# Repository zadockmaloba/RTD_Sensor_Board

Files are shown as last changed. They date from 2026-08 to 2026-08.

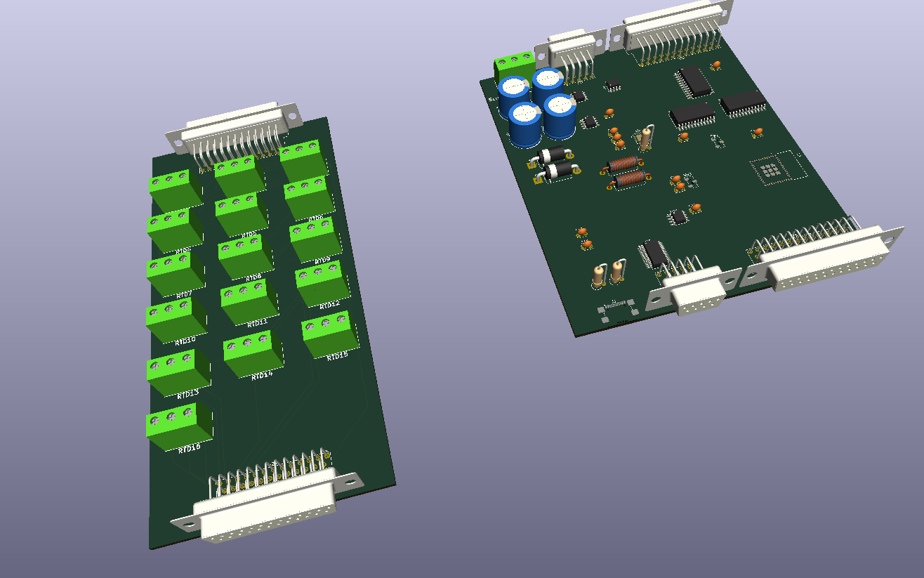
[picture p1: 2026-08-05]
schematics/sensor_node_custom_board.png

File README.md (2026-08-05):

# Zadock Maloba - Instrumentation & Control Engineer Design Challenge

## The System

A lab-scale thermal test bench. Sixteen RTDs are distributed along a heated circuit; a
coolant admission valve opens and closes to hold the circuit within band. The bench runs
unattended for days at a time, and the resulting temperature record is the deliverable that
engineers downstream actually care about.

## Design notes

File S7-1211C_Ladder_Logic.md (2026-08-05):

# S7-1211C Ladder Logic

## 1. Purpose

This document describes the derived ladder logic for the Siemens S7-1211C CPU with CB1241 communication module used in the thermal test bench. The logic reads RTD temperature data from the IPC via Modbus, evaluates interlock conditions, and controls the coolant valve.

## 2. Assumptions

- The PLC uses the CB1241 for RS-485 Modbus communication with the IPC.
- The IPC exposes RTD temperatures and status values in Modbus registers.
- The PLC executes a read cycle every `100 ms`.
- The valve coil is controlled by output `Q0.0`.
- Valve feedback is available in Modbus register `VALVE_STATUS`.

## 3. Data Block Mapping

Use `DB1` to map Modbus register values into PLC memory.

| DB1 Offset | Description |
|---|---|
| `DB1.W0` | SYSTEM_STATUS |
| `DB1.W1` | NODE_HEALTH |
| `DB1.W2` | RTD_01 |
| `DB1.W3` | RTD_02 |
| `DB1.W4` | RTD_03 |
| `DB1.W5` | RTD_04 |
| `DB1.W6` | RTD_05 |
| `DB1.W7` | RTD_06 |
| `DB1.W8` | RTD_07 |
| `DB1.W9` | RTD_08 |
| `DB1.W10` | RTD_09 |
| `DB1.W11` | RTD_10 |
| `DB1.W12` | RTD_11 |
| `DB1.W13` | RTD_12 |
| `DB1.W14` | RTD_13 |
| `DB1.W15` | RTD_14 |
| `DB1.W16` | RTD_15 |
| `DB1.W17` | RTD_16 |
| `DB1.W18` | RTD_FAULT_BITMAP |
| `DB1.W19` | INTERLOCK_SOURCE |
| `DB1.W20` | VALVE_COMMAND |
| `DB1.W21` | VALVE_STATUS |
| `DB1.W22` | PROCESS_SETPOINT |
| `DB1.W23` | ALARM_THRESHOLD |
| `DB1.W24` | DIAGNOSTICS_CODE |

## 4. Internal Memory Bits

| Bit | Name | Description |
|---|---|---|
| `M0.0` | MODBUS_OK | Modbus communication healthy |
| `M0.1` | RTD_FAULT_PRESENT | Any RTD fault or invalid data present |
| `M0.2` | TEMP_BELOW_SP | Selected temperature below setpoint |
| `M0.3` | TEMP_ABOVE_ALARM | Selected temperature above alarm threshold |
| `M0.4` | VALVE_OPEN_REQUEST | Automatic open request |
| `M0.5` | VALVE_CLOSE_REQUEST | Automatic close request / safe close |
| `M0.6` | MANUAL_OVERRIDE_ACTIVE | Manual command override active |

## 5. Ladder Logic Rungs

### Rung 1: Modbus Health Decode

- Set `M0.0` when `SYSTEM_STATUS.bit1` (`MODBUS_OK`) is true.
- Set `M0.1` when `SYSTEM_STATUS.bit2` (`RTD_FAULT`) is true or `RTD_FAULT_BITMAP <> 0`.

```
  [ DB1.W0.1 ] --------------------( ) M0.0
  [ DB1.W0.2 ] --------------------( ) M0.1
  [ DB1.W18 <> 0 ] ---------------( ) M0.1
```

### Rung 2: Temperature Source Selection

Select the active temperature used for control based on `INTERLOCK_SOURCE`:

- `0` or `1`: maximum of RTD1..RTD16
- `2`: average of RTD1..RTD16

Store the result in `MW100` (`SELECTED_TEMP`).

> Note: This can be implemented with a function block, a structured organization block, or a set of compare/move instructions.

### Rung 3: Temperature Comparison

Compare `SELECTED_TEMP` to the setpoint and alarm threshold.

```
  [ MW100 < DB1.W22 ]  ----------( ) M0.2
  [ MW100 >= DB1.W23 ] -----------( ) M0.3
```

### Rung 4: Safe-close Condition

Request safe close when any fault or alarm exists, or when Modbus is down.

```
  [ NOT M0.0 ] --------------------( ) M0.5
  [ M0.1 ] ------------------------( ) M0.5
  [ M0.3 ] ------------------------( ) M0.5
```

### Rung 5: Auto Valve Decision

In auto mode, open if below setpoint and no fault; otherwise close.

```
  [ M0.0 ] [ NOT M0.1 ] [ M0.2 ] --( ) M0.4
  [ M0.5 ] -----------------------( ) /M0.4
```

### Rung 6: Manual Override

If manual override is active, use `VALVE_COMMAND` from the IPC instead of the auto request.

```
  [ M0.6 ] [ DB1.W20 = 1 ] ------( ) Q0.0
  [ M0.6 ] [ DB1.W20 = 2 ] ------( ) /Q0.0
  [ NOT M0.6 ] [ M0.4 ] ---------( ) Q0.0
  [ NOT M0.6 ] [ /M0.4 ] --------( ) /Q0.0
```

### Rung 7: Valve Feedback Validation

Raise a fault if the commanded valve position does not match feedback.

```
  [ Q0.0 ] [ DB1.W21 = 0 ] -----( ) M0.1
  [ /Q0.0 ] [ DB1.W21 = 1 ] ----( ) M0.1
```

## 6. Control Flow Summary

1. Read Modbus registers from IPC into `DB1`.
2. Decode communication and sensor faults.
3. Select the temperature value used for the safety interlock.
4. Compare against setpoint and alarm threshold.
5. Determine auto open/close commands.
6. Override with manual commands if active.
7. Drive `Q0.0` for the valve coil.
8. Validate feedback and set fault state if mismatch detected.

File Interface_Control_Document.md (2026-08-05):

# Interface Control Document (ICD)

## 1. System Overview

This ICD covers the runtime interface for the lab-scale thermal test bench, with the following logical components:

- **RTD field sensors**: 16 PT1000 / PT100 RTDs distributed along the heated circuit.
- **Sensor Node**: local acquisition board that reads all 16 RTDs and forwards temperature data over CAN.
- **IPC (Industrial PC)**: collects CAN data and exposes it to the PLC via Modbus RTU. Also publishes higher-level telemetry by MQTT.
- **PLC (Siemens S7-1211C)**: performs control and a safety interlock, and actuates the coolant admission valve.
- **Valve**: final control element driven from the PLC output.

Physical connections:

- 24 VDC power to PLC, Sensor Node, and IPC.
- CAN bus between Sensor Node and IPC using DB9 connectors.
- Modbus RTU over RS-485 between IPC and PLC.
- Valve output from the PLC and RTD inputs to the Sensor Node.

This ICD defines the communication and timing interfaces for the sensor-to-controller/actuator path.

---

## 2. Modbus Register Map

### 2.1 Modbus Role and Transport

- **Modbus mode**: RTU
- **Byte order**: 8-bit bytes, least-significant bit first in each byte.
- **Frame format**: [Address][Function][Data][CRC16]
- **Character format**: 8 data bits, no parity, 1 stop bit (8N1) unless otherwise configured.
- **Default baud rate**: 19200 bps. Implementation must support up to 115200 bps.
- **Slave address**: `1` (modifiable by configuration).
- **Master**: Siemens S7-1211C PLC.
- **Slave**: IPC / Modbus bridge.

### 2.2 Function Codes Supported

- `0x03` Read Holding Registers
- `0x04` Read Input Registers
- `0x06` Write Single Register
- `0x10` Write Multiple Registers

### 2.3 Register Addressing

Modbus register addresses are shown in the conventional 40001-style notation. Implementation uses zero-based register indices internally.

- `40001` → register index `0`
- `40002` → register index `1`
- ...

### 2.4 Data Types and Scaling

- `INT16` — signed 16-bit integer.
- `UINT16` — unsigned 16-bit integer.
- `INT32` — signed 32-bit integer (uses two consecutive registers; high order register first).
- Scalar units:
  - Temperature: `0.01 °C` per count.
  - Valve command: unitless percentage / discrete state.

### 2.5 Byte and Word Order

- Within each Modbus register, bytes are transmitted MSB first.
- For 32-bit values spanning two registers, the **high-order register is transmitted first**, followed by the low-order register.
- Example: `INT32` value `0x12345678` is mapped to registers `[0x1234, 0x5678]`.

### 2.6 Register Map

| Address | Name | Type | Access | Scaling | Description |
|---|---|---|---|---|---|
| 40001 | SYSTEM_STATUS | UINT16 | R | Bitfield | Node and bridge status. Bit definitions below. |
| 40002 | NODE_HEALTH | UINT16 | R | Raw | Sensor node health code / error code. |
| 40003 | RTD_01 | INT16 | R | 0.01 °C | RTD channel 1 temperature. |
| 40004 | RTD_02 | INT16 | R | 0.01 °C | RTD channel 2 temperature. |
| 40005 | RTD_03 | INT16 | R | 0.01 °C | RTD channel 3 temperature. |
| 40006 | RTD_04 | INT16 | R | 0.01 °C | RTD channel 4 temperature. |
| 40007 | RTD_05 | INT16 | R | 0.01 °C | RTD channel 5 temperature. |
| 40008 | RTD_06 | INT16 | R | 0.01 °C | RTD channel 6 temperature. |
| 40009 | RTD_07 | INT16 | R | 0.01 °C | RTD channel 7 temperature. |
| 40010 | RTD_08 | INT16 | R | 0.01 °C | RTD channel 8 temperature. |
| 40011 | RTD_09 | INT16 | R | 0.01 °C | RTD channel 9 temperature. |
| 40012 | RTD_10 | INT16 | R | 0.01 °C | RTD channel 10 temperature. |
| 40013 | RTD_11 | INT16 | R | 0.01 °C | RTD channel 11 temperature. |
| 40014 | RTD_12 | INT16 | R | 0.01 °C | RTD channel 12 temperature. |
| 40015 | RTD_13 | INT16 | R | 0.01 °C | RTD channel 13 temperature. |
| 40016 | RTD_14 | INT16 | R | 0.01 °C | RTD channel 14 temperature. |
| 40017 | RTD_15 | INT16 | R | 0.01 °C | RTD channel 15 temperature. |
| 40018 | RTD_16 | INT16 | R | 0.01 °C | RTD channel 16 temperature. |
| 40019 | RTD_FAULT_BITMAP | UINT16 | R | Bitfield | RTD channel fault indicators: bit 0 = RTD1 fault, ... bit 15 = RTD16 fault. |
| 40020 | INTERLOCK_SOURCE | UINT16 | R/W | Raw | Interlock source selection; 0=automatic, 1=RTD max, 2=RTD average, reserved values. |
| 40021 | VALVE_COMMAND | UINT16 | R/W | 0=close, 1=open, 2=auto | Valve request command for supervisory override. |
| 40022 | VALVE_STATUS | UINT16 | R | 0/1 | Actual valve feedback state: 0=closed, 1=open. |
| 40023 | PROCESS_SETPOINT | INT16 | R/W | 0.01 °C | Desired process temperature setpoint. |
| 40024 | ALARM_THRESHOLD | INT16 | R/W | 0.01 °C | High temperature alarm threshold. |
| 40025 | DIAGNOSTICS_CODE | UINT16 | R | Raw | Bridge diagnostics or fault code. |
| 40026 | TIMESTAMP_LOW | UINT16 | R | ms | Low 16 bits of sample timestamp, optional. |
| 40027 | TIMESTAMP_HIGH | UINT16 | R | ms | High 16 bits of sample timestamp, optional. |

### 2.7 SYSTEM_STATUS Bitfield

| Bit | Name | Description |
|---|---|---|
| 0 | CAN_OK | 1 = CAN uplink active, 0 = CAN error detected |
| 1 | MODBUS_OK | 1 = Modbus connection healthy, 0 = Modbus error |
| 2 | RTD_FAULT | 1 = any RTD fault present |
| 3 | VALVE_FAULT | 1 = valve feedback mismatch or actuator fault |
| 4 | NODE_HEALTH_WARN | 1 = warning state |
| 5 | IPC_HEALTH_WARN | 1 = IPC bridge warning |
| 6 | RESERVED | Reserved for future use |
| 7 | RESERVED | Reserved for future use |
| 8..15 | RESERVED | Reserved for future expansion |

### 2.8 Access Rights Summary

- Read-only: RTD_01..RTD_16, RTD_FAULT_BITMAP, VALVE_STATUS, DIAGNOSTICS_CODE, TIMESTAMP_LOW/HIGH.
- Read/write: INTERLOCK_SOURCE, VALVE_COMMAND, PROCESS_SETPOINT, ALARM_THRESHOLD.
- Write access should only be granted to authorized PLC logic and must be validated by the IPC bridge.

### 2.9 Error Handling

- Modbus exception codes must be returned per Modbus RTU specification.
- If a temperature value is invalid or out of range, the IPC shall set the corresponding RTD register to `0x8000` and set the RTD fault bit.
- CRC checks are mandatory on every RTU frame.

---

## 3. CAN Frame Catalogue

### 3.1 CAN Bus Overview

- **CAN type**: Classic CAN
- **Identifier**: 11-bit standard IDs
- **Nominal bitrate**: `500 kbps`
- **Bus topology**: single-wire differential pair over DB9.
- **Physical node**: Sensor Node is producer of temperature frames; IPC is consumer and Modbus bridge.

### 3.2 Frame Priority Rationale

CAN arbitration uses lower IDs as higher priority. The mapping ensures:

- safety and status frames win arbitration over periodic temperature data.
- temperature data is grouped into equal-sized frames for deterministic bandwidth.

### 3.3 Frame Definitions

| CAN ID | Name | Direction | Data Length | Frequency | Description |
|---|---|---|---|---|---|
| `0x100` | RTD_GROUP_1 | Node → IPC | 8 | 10 Hz | RTD1..RTD4 temperatures. |
| `0x101` | RTD_GROUP_2 | Node → IPC | 8 | 10 Hz | RTD5..RTD8 temperatures. |
| `0x102` | RTD_GROUP_3 | Node → IPC | 8 | 10 Hz | RTD9..RTD12 temperatures. |
| `0x103` | RTD_GROUP_4 | Node → IPC | 8 | 10 Hz | RTD13..RTD16 temperatures. |
| `0x110` | NODE_DIAGNOSTICS | Node → IPC | 8 | 1 Hz | Node health, scan status, and fault bitmap. |
| `0x120` | BRIDGE_STATUS | IPC → PLC/Node | 8 | 1 Hz | IPC-to-PLC bridge heartbeat and system health. |
| `0x130` | VALVE_COMMAND | IPC/PLC → Node | 8 | Event-driven up to 10 Hz | Supervisory valve command or override. |

### 3.4 RTD Multiplexing Layout

Each RTD group frame carries four channels; this is the multiplexing strategy used so 16 channels fit within the 8-byte CAN payload.

#### `0x100` `RTD_GROUP_1`

| Byte | Contents |
|---|---|
| 0..1 | RTD1 temperature (INT16, 0.01 °C) |
| 2..3 | RTD2 temperature (INT16, 0.01 °C) |
| 4..5 | RTD3 temperature (INT16, 0.01 °C) |
| 6..7 | RTD4 temperature (INT16, 0.01 °C) |

#### `0x101` `RTD_GROUP_2`

| Byte | Contents |
|---|---|
| 0..1 | RTD5 temperature |
| 2..3 | RTD6 temperature |
| 4..5 | RTD7 temperature |
| 6..7 | RTD8 temperature |

#### `0x102` `RTD_GROUP_3`

| Byte | Contents |
|---|---|
| 0..1 | RTD9 temperature |
| 2..3 | RTD10 temperature |
| 4..5 | RTD11 temperature |
| 6..7 | RTD12 temperature |

#### `0x103` `RTD_GROUP_4`

| Byte | Contents |
|---|---|
| 0..1 | RTD13 temperature |
| 2..3 | RTD14 temperature |
| 4..5 | RTD15 temperature |
| 6..7 | RTD16 temperature |

### 3.5 Diagnostic Frame Layout

#### `0x110` `NODE_DIAGNOSTICS`

| Byte | Field | Description |
|---|---|---|
| 0 | STATUS_FLAGS | Bitfield; bit 0=CAN_OK, bit1=RTD_FAULT, bit2=MODBUS_OK, bit3=VALVE_FAULT. |
| 1 | ERROR_CODE | Node-specific health code. |
| 2 | SAMPLE_COUNTER | Rolling frame counter (0..255). |
| 3 | RESERVED | Reserved, set to 0. |
| 4..5 | FAULT_BITMAP | 16-bit RTD fault bitmap (big-endian). |
| 6..7 | RESERVED | Reserved, set to 0. |

### 3.6 Valve Command Frame Layout

#### `0x130` `VALVE_COMMAND`

| Byte | Field | Description |
|---|---|---|
| 0 | COMMAND_TYPE | `0x00` = no action / auto, `0x01` = open, `0x02` = close, `0x03` = override. |
| 1 | COMMAND_VALUE | 0..100 for percentage or duty; reserved if discrete. |
| 2 | FLAGS | bit0=valid, bit1=override active, others reserved. |
| 3 | RESERVED | Reserved, set to 0. |
| 4..5 | INTERLOCK_SETPOINT | INT16 0.01°C if command is temperature-targeted. |
| 6..7 | CHECKSUM | Simple ID+data checksum for application-layer validation. |

### 3.7 CAN Timing and Bus Loading

#### Frame timing

- `RTD_GROUP_*` frames at `10 Hz` each.
- `NODE_DIAGNOSTICS` at `1 Hz`.
- `BRIDGE_STATUS` at `1 Hz`.
- `VALVE_COMMAND` event-driven; worst-case `10 Hz`.

#### Frame bit count

For Classic CAN standard frame with 8 bytes of data:

- Payload bits = `8 bytes * 8 = 64 bits`
- Overhead estimate = `47 bits`
- Total per frame ≈ `111 bits`

#### Worst-case bus loading (500 kbps)

- 4 RTD frames at 10 Hz: `4 * 111 * 10 = 4,440 bits/s`
- `NODE_DIAGNOSTICS` at 1 Hz: `111 bits/s`
- `BRIDGE_STATUS` at 1 Hz: `111 bits/s`
- `VALVE_COMMAND` at 10 Hz worst-case: `1,110 bits/s`

**Total worst-case** ≈ `5,772 bits/s` or `1.16%` of a `500 kbps` bus.

#### Worst-case bus loading (250 kbps)

**Total worst-case** ≈ `2.31%` of the bus.

For additional safety, the design budget should reserve at least `10%` of bus capacity for future frames, retransmissions, and error recovery.

### 3.8 Multiplexing Justification

Classic CAN affords only 8 bytes per frame, while the system must transport 16 temperature channels. The chosen multiplexing groups four RTDs per frame and transmits all four group frames at 10 Hz. This delivers all 16 temperatures every 100 ms while keeping bus loading extremely low.

---

## 4. Timing Requirements

### 4.1 Sensor Node Acquisition

- Sample interval: `100 ms` nominal.
- Conversion latency: `20 ms` maximum for a full RTD scan and temperature calculation.
- CAN transmit delay: `< 10 ms` from measurement ready to first eligible CAN frame.

### 4.2 PLC Polling and Scan

- PLC poll interval for Modbus: `100 ms` nominal.
- PLC scan interval / logic update: `50 ms` nominal, with worst-case `100 ms`.
- Combined worst-case PLC update interval: `200 ms` if polling and scan align unfavorably.

### 4.3 Modbus Response Latency

At `19200 bps`, a single Modbus RTU request/response pair of roughly 8 bytes each takes approximately `27 ms` each direction, plus up to `10 ms` processing inside the bridge.

- Request latency: `27 ms`
- Response latency: `27 ms`
- Total Modbus round-trip: `~60 ms`

### 4.4 End-to-End Latency Budget

The chain is:

1. RTD analog acquisition and digital conversion.
2. Sensor node CAN transmission.
3. IPC CAN reception and Modbus register update.
4. PLC Modbus request, scan, and logic execution.
5. Valve output update and coil response.

#### Worst-case budget estimate

| Stage | Budget |
|---|---|
| RTD acquisition and conversion | 20 ms |
| CAN transmission + arbitration | 50 ms |
| IPC processing / Modbus register write | 10 ms |
| PLC Modbus poll wait | 100 ms |
| PLC logic scan and output update | 20 ms |
| Valve coil actuation delay | 50 ms |
| **Total worst-case** | **250 ms** |

### 4.5 Value Age for Safety Interlock

- The PLC reads the latest RTD values from Modbus once per poll cycle.
- The worst-case age of the RTD value used by the interlock is:
  - RTD sample age at the moment of CAN transmission: up to `100 ms`
  - CAN delivery and IPC update: up to `50 ms`
  - Modbus poll interval: `100 ms`

**Worst-case interlock age**: `~250 ms`

### 4.6 Safety Margin and Refresh Rate

- The RTD data refresh rate should remain at least `10 Hz`.
- The interlock decision interval must be no slower than `200 ms`.
- The recommended implementation is to maintain the last good temperature sample in the IPC and continue supplying it to the PLC until a new sample completes successfully.

---

## 5. Use Cases and Data Flow

### 5.1 Normal Operation

1. The Sensor Node reads 16 RTDs and computes temperatures.
2. Every `100 ms`, the Sensor Node sends four CAN frames (`0x100`..`0x103`) containing the 16 temperature values.
3. The IPC receives the CAN frames, updates its internal temperature table, and presents values in Modbus registers `40003`..`40018`.
4. The PLC polls those registers at `100 ms` intervals, computes control and interlock decisions, and updates the valve output.

### 5.2 Fault Handling

- If any RTD is invalid, the Sensor Node sets the corresponding `RTD_FAULT_BITMAP` bit and sends `0x110` status with fault details.
- The IPC sets `SYSTEM_STATUS` accordingly and reports the fault to the PLC via `40019`.
- The PLC may enter a safe state if a fault bit is asserted.

### 5.3 Valve Override

- Supervisory or maintenance command may be issued using `VALVE_COMMAND` via Modbus or by CAN command `0x130`.
- The PLC must validate override requests and compare them against `INTERLOCK_SOURCE`, `PROCESS_SETPOINT`, and `ALARM_THRESHOLD`.

---

## 6. Assumptions and Notes

This ICD is derived from the provided system architecture, available schematic annotations, and typical industrial network patterns. Specific hardware parameters that are not present in the repository are handled using standard industrial defaults:

- Modbus RTU at 19200 bps unless otherwise constrained.
- Classic CAN with 11-bit identifiers and 500 kbps nominal speed.
- RTD scaling to `0.01 °C` for precision.

If the final implementation uses alternate baud rates, a longer Modbus register range, or extended CAN identifiers, those details must be updated in this ICD.

---

## 7. Revision History

- `1.0` — Initial ICD for RTD-to-valve interface, including Modbus register map, CAN frame catalogue, and timing budgets.

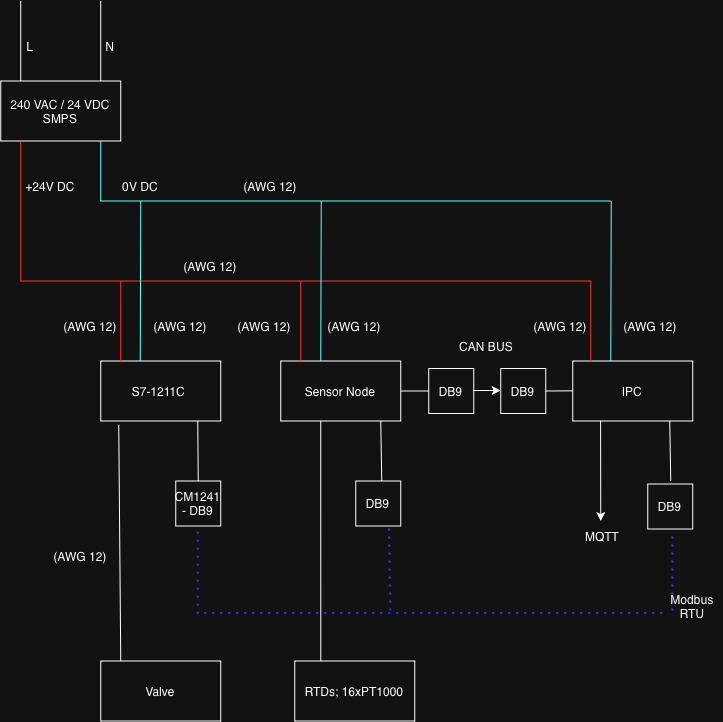
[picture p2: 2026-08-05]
Zadock_Octavia_Carbon.drawio.png

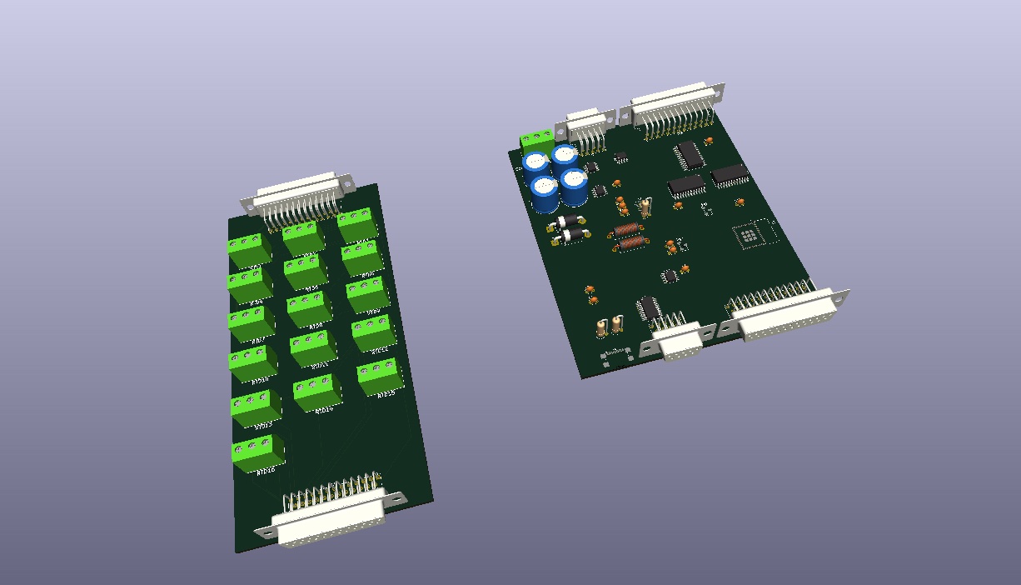
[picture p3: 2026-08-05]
Board Render.jpg

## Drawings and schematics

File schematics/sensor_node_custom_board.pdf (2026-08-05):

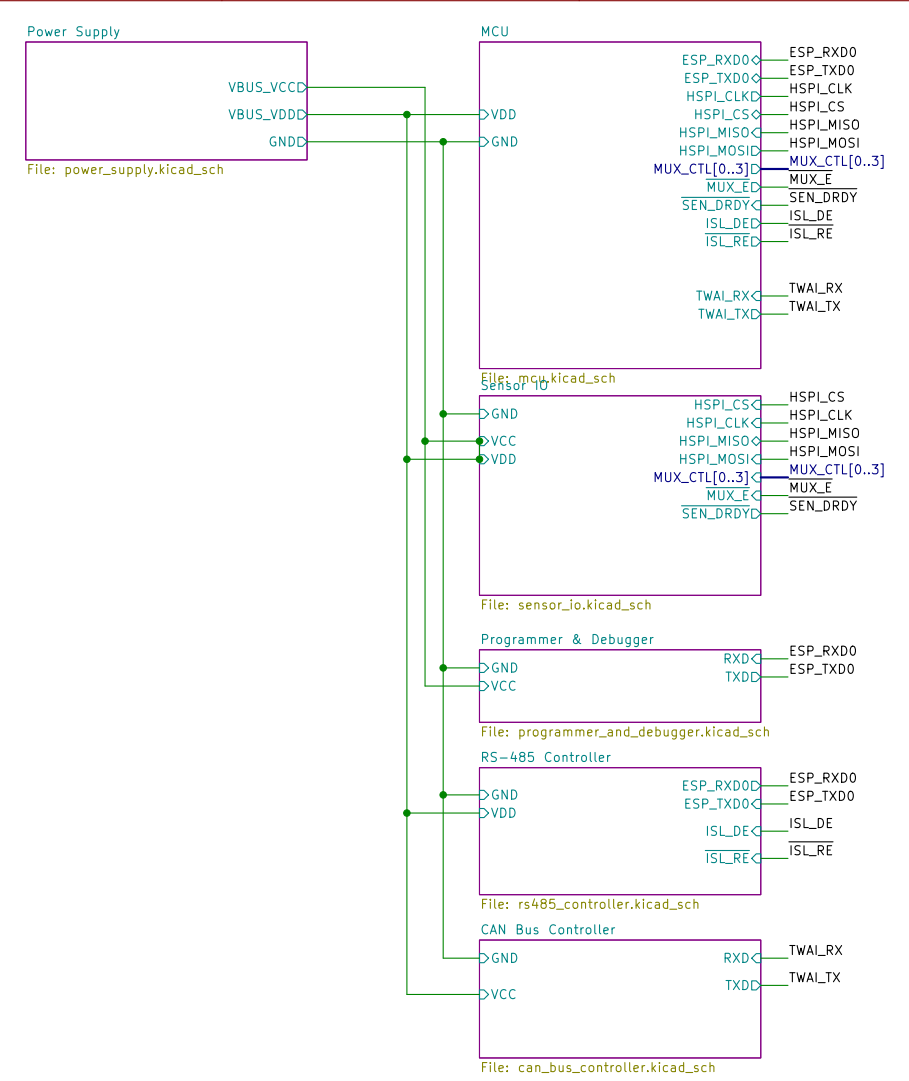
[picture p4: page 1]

CAN Bus Controller File: can_bus_controller.kicad_sch

Zadock Maloba
Octavia Carbon
Sheet: /Control Board/
File: sensor_node_custom_board.kicad_sch
Title: Sensor Node Custom Board

Size: A4 | Rev: 1
KiCad E.D.A. 10.0.3 | Id: 1/9

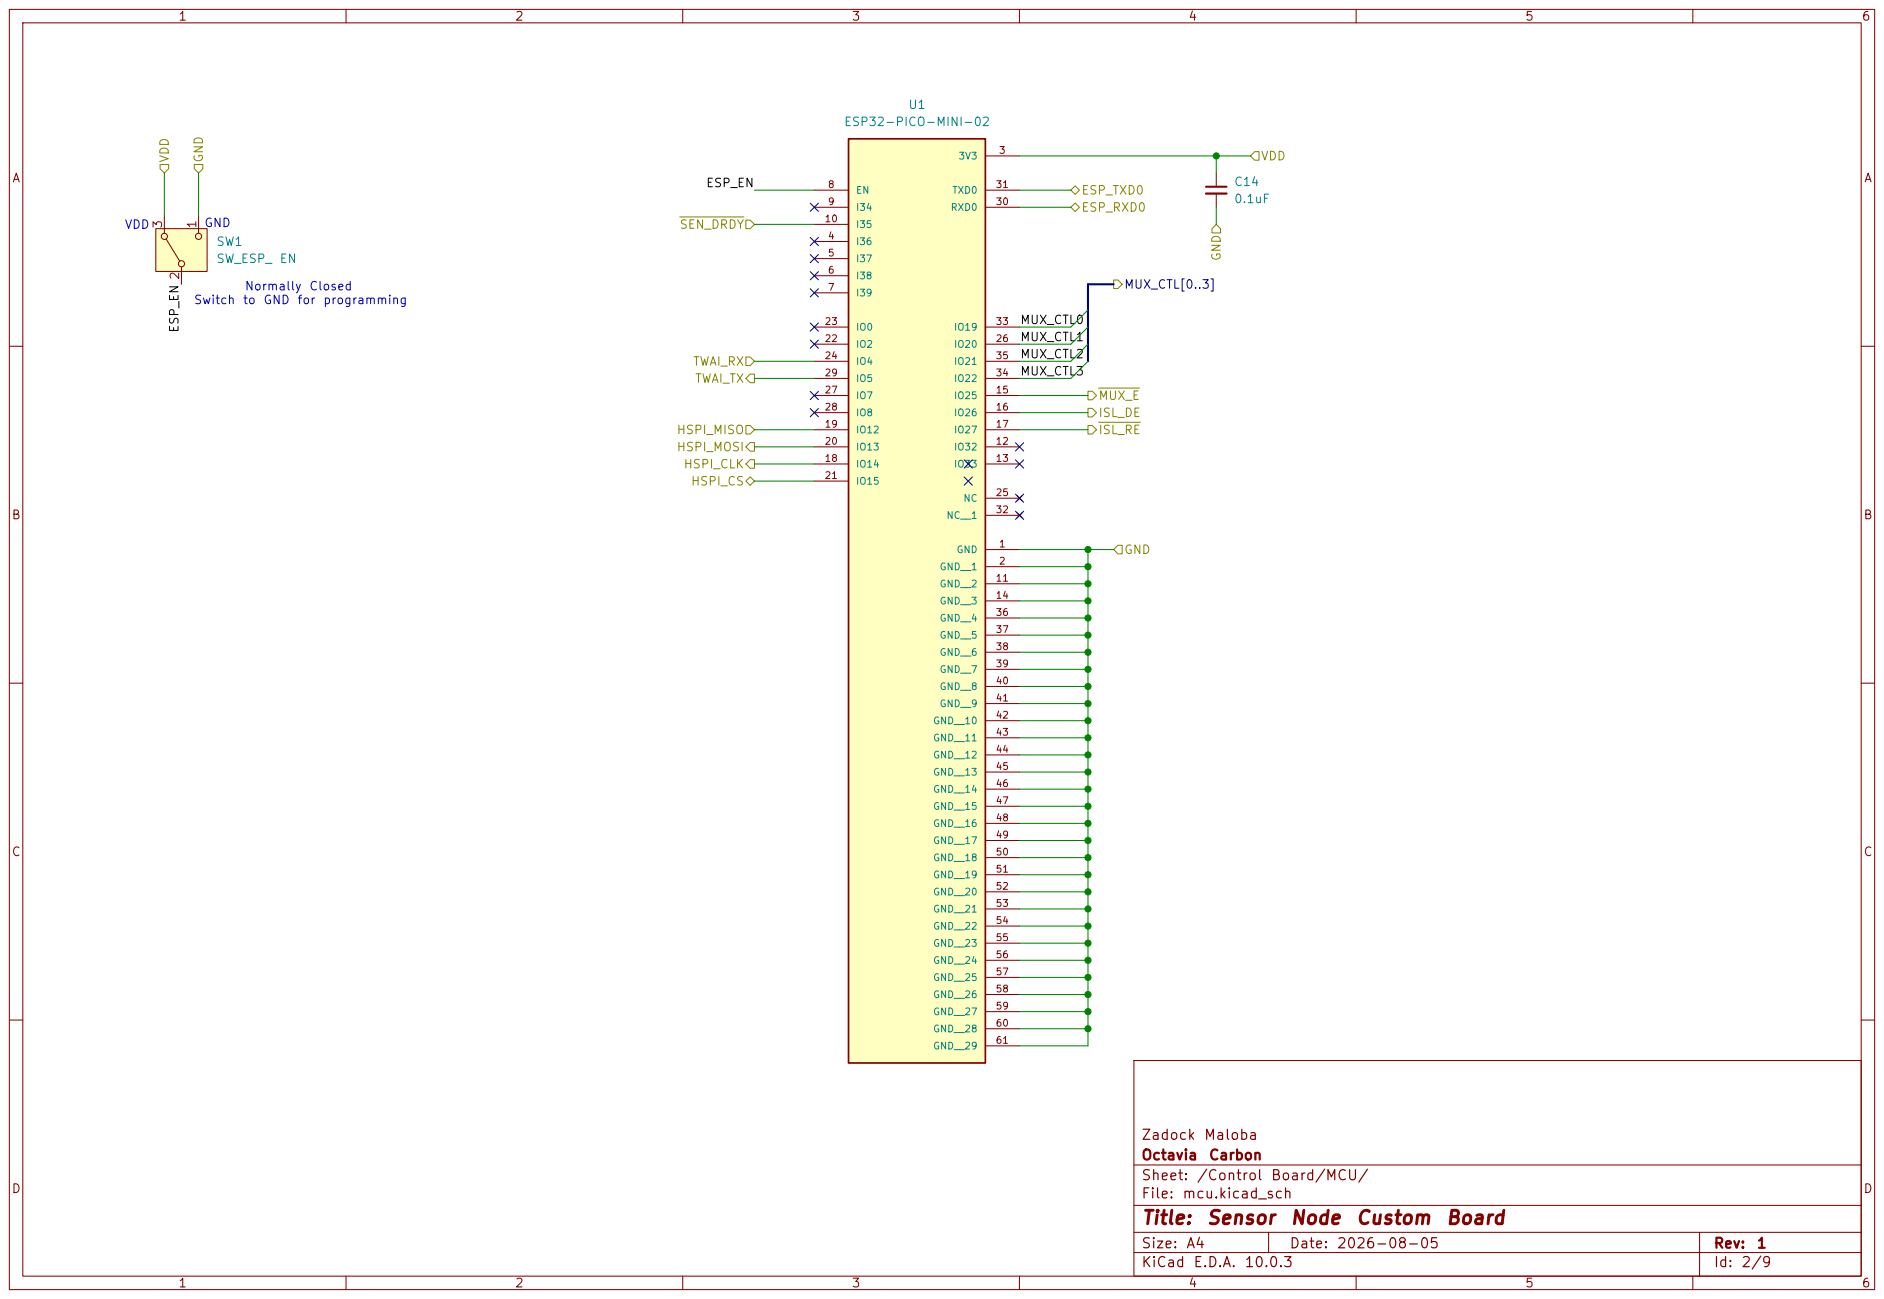
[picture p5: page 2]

Zadock Maloba
Octavia Carbon
Sheet: /Control Board/MCU/
File: mcu.kicad_sch
Title: Sensor Node Custom Board

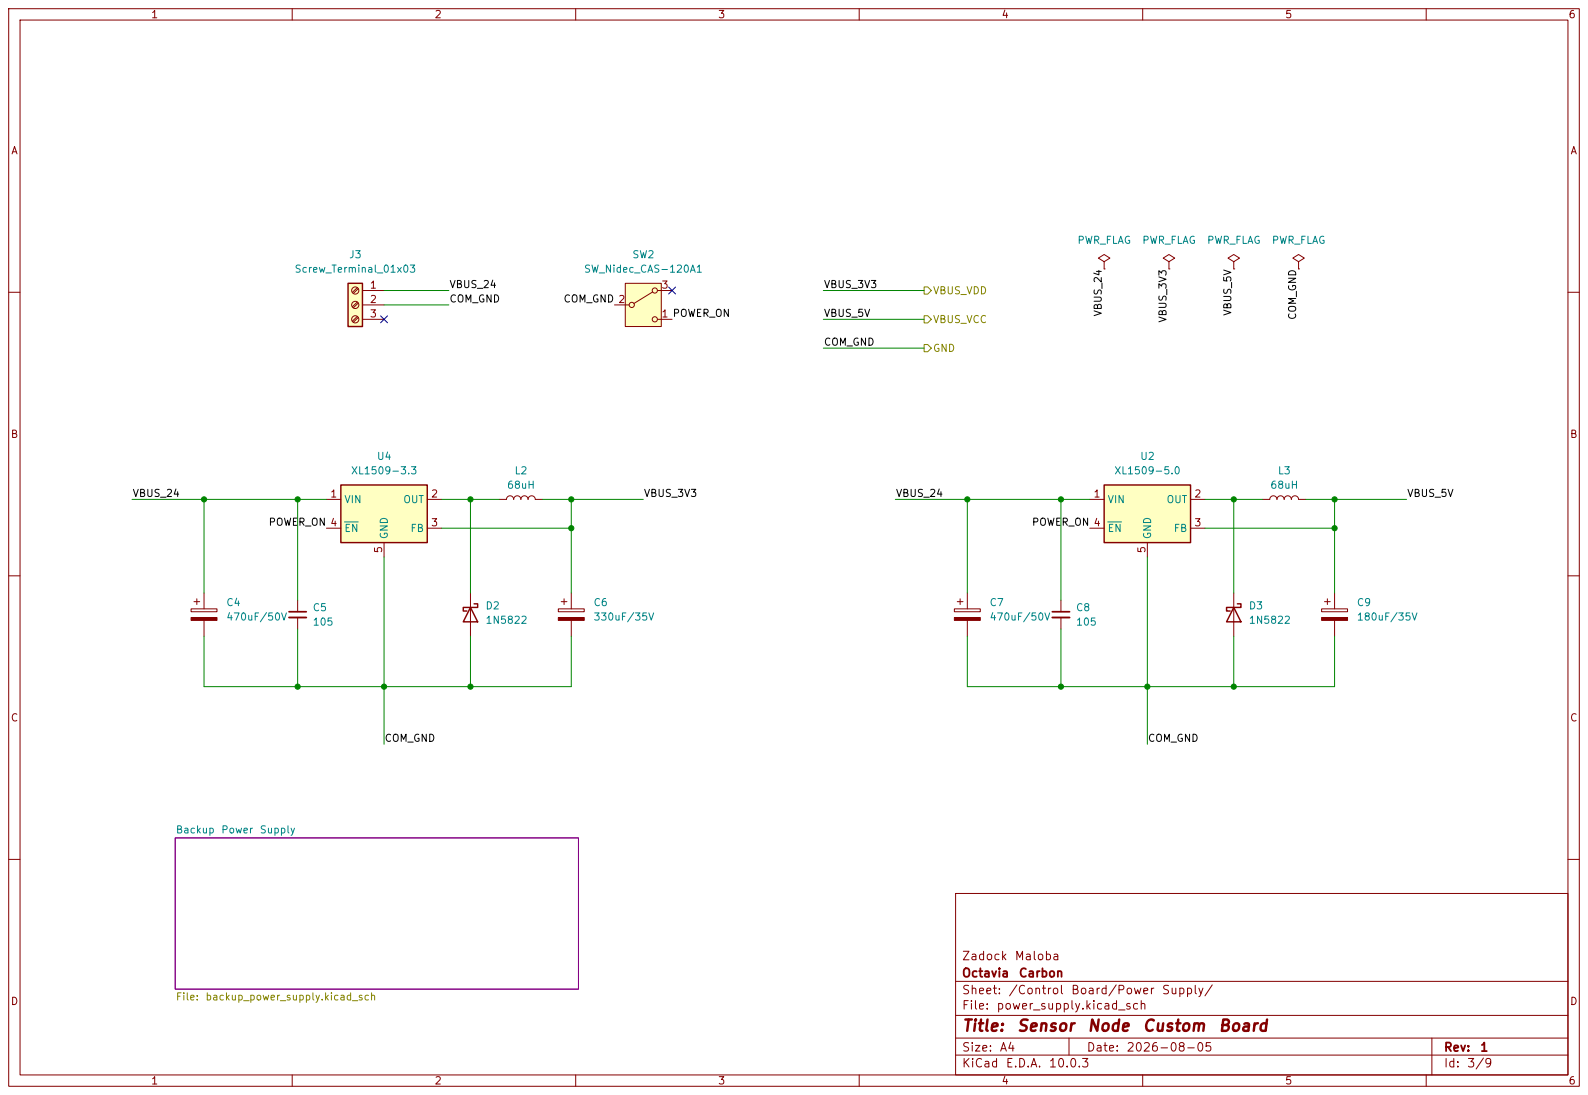
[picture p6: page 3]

Backup Power Supply File: backup_power_supply.kicad_sch

Zadock Maloba
Octavia Carbon
Sheet: /Control Board/Power Supply/
File: power_supply.kicad_sch
Title: Sensor Node Custom Board

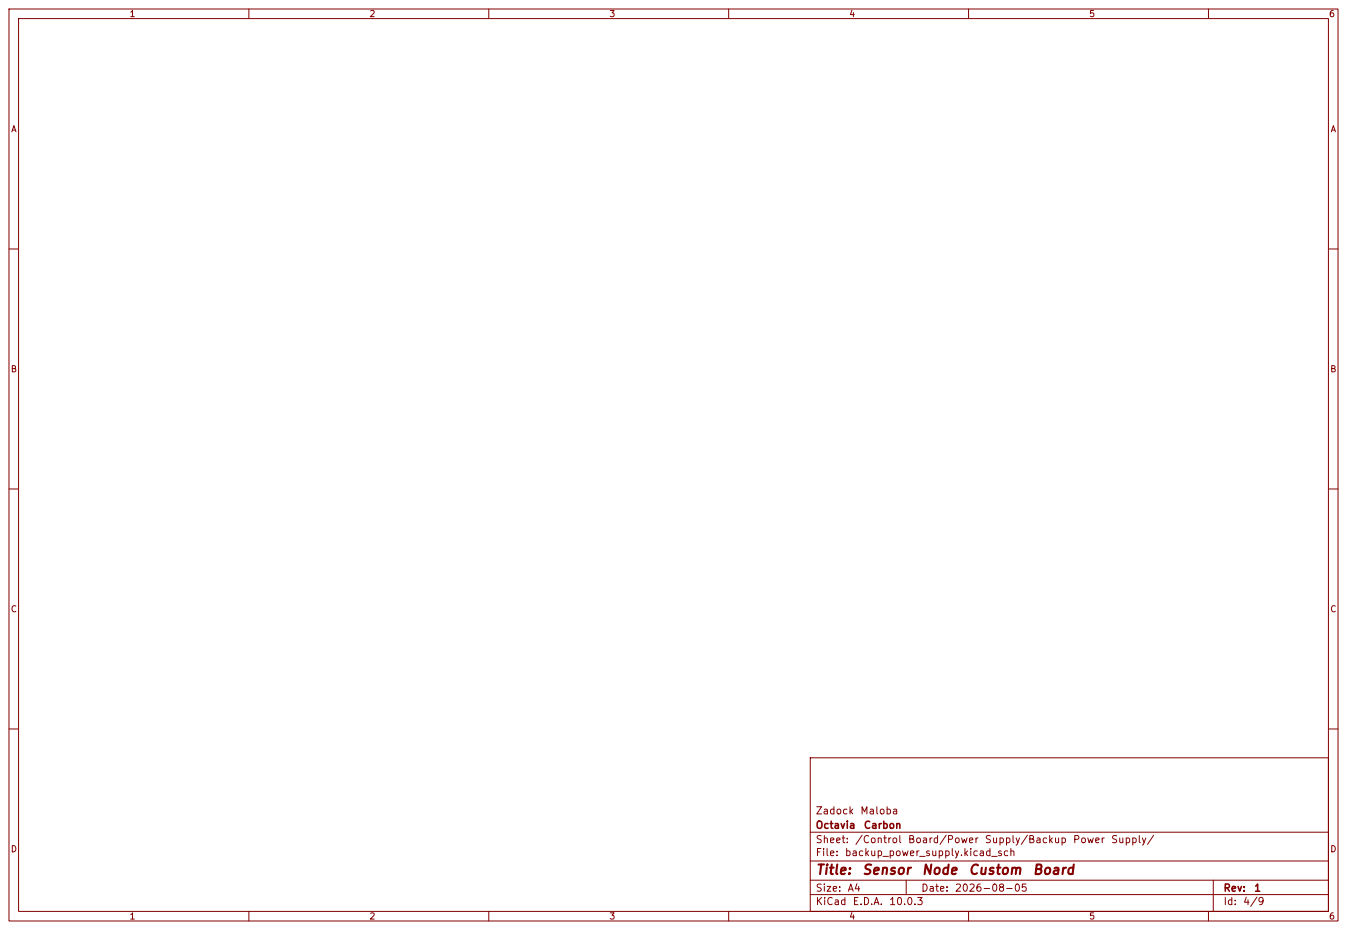
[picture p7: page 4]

Zadock Maloba
Octavia Carbon
Sheet: /Control Board/Power Supply/Backup Power Supply/
File: backup_power_supply.kicad_sch
Title: Sensor Node Custom Board

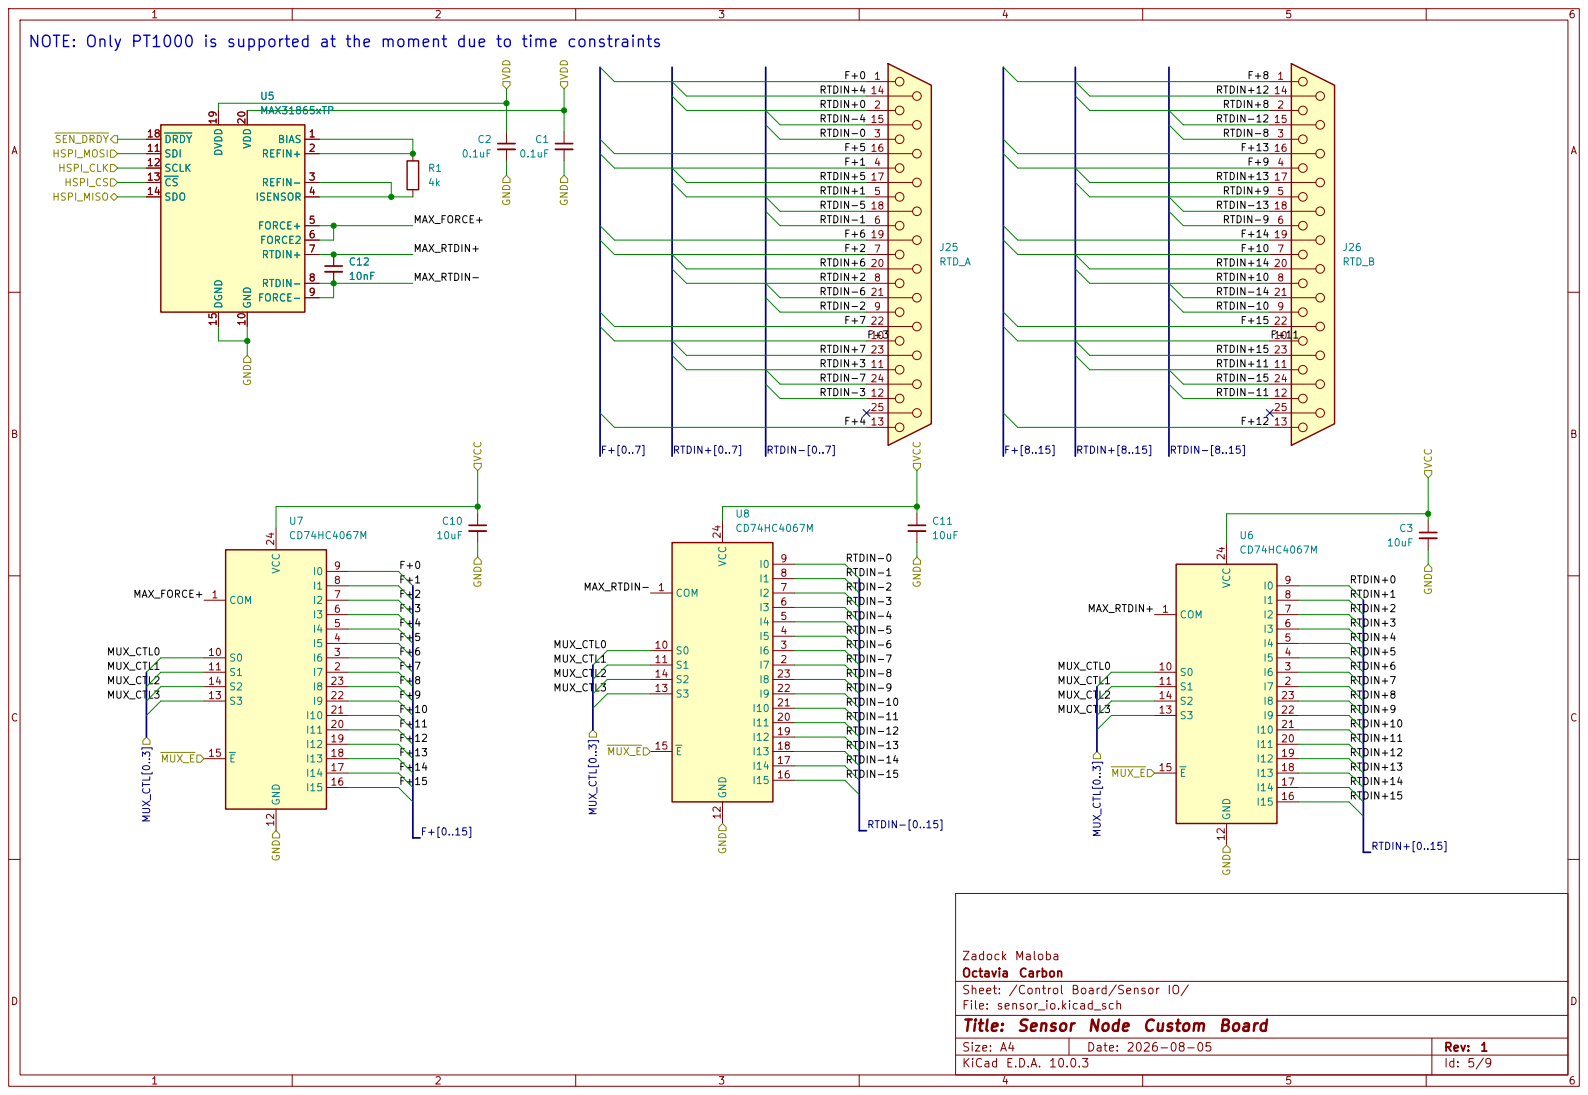
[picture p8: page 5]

RTDIN-14 NOTE: Only PT1000 is supported at the moment due to time constraints

RTDIN-8 RTDIN-10 RTDIN-9 RTDIN-7 RTDIN-11 RTDIN-12

Zadock Maloba
Octavia Carbon
Sheet: /Control Board/Sensor IO/
File: sensor_io.kicad_sch
Title: Sensor Node Custom Board

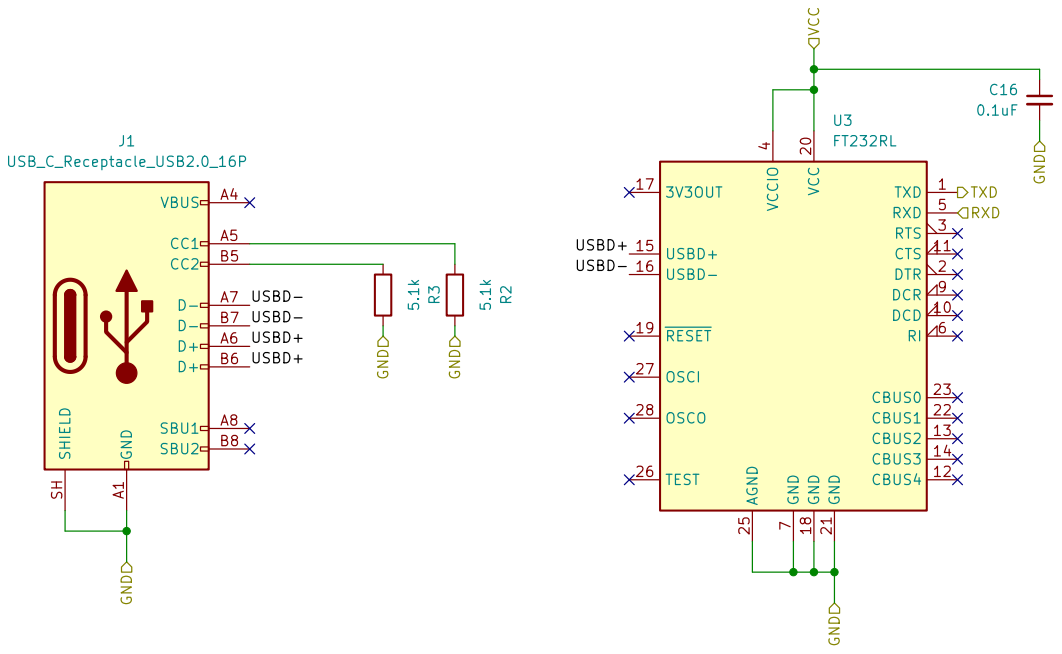
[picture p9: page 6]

7 DCR 9 DCD 10 CTS 11 CBUS4 12 CBUS2 13 CBUS3 14 USBD+ 15 USBD- 16

Zadock Maloba
Octavia Carbon
Sheet: /Control Board/Programmer & Debugger/
File: programmer_and_debugger.kicad_sch
Title: Sensor Node Custom Board

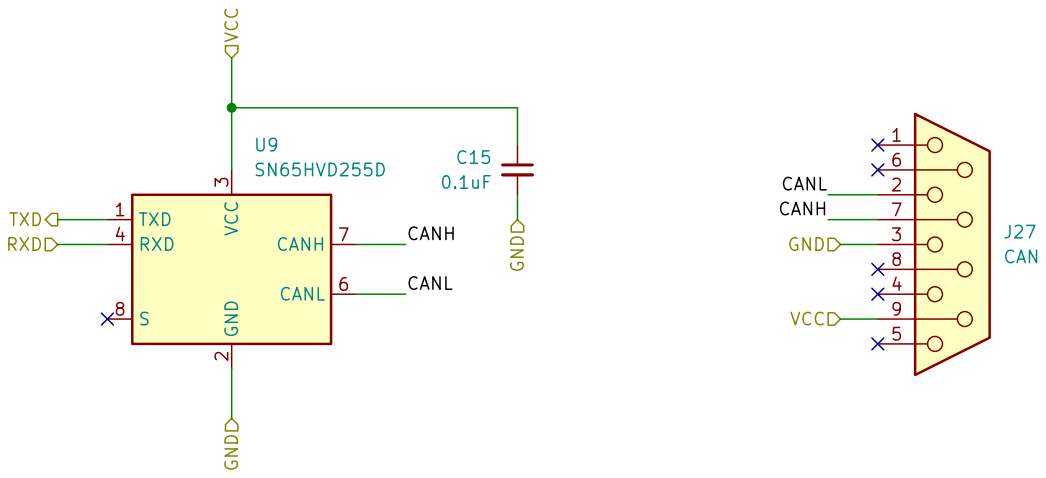
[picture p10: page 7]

Zadock Maloba
Octavia Carbon
Sheet: /Control Board/CAN Bus Controller/
File: can_bus_controller.kicad_sch
Title: Sensor Node Custom Board

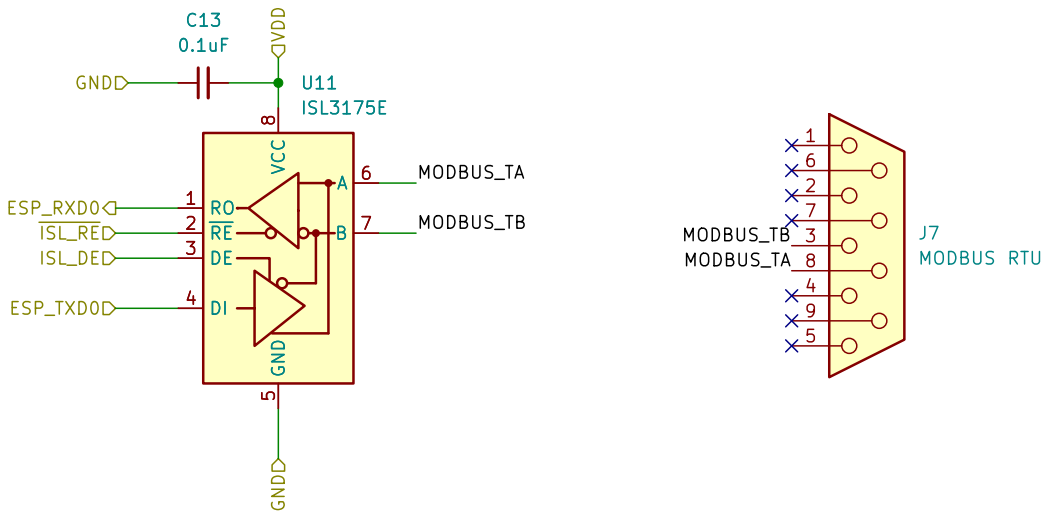
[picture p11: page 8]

Zadock Maloba
Octavia Carbon
Sheet: /Control Board/RS-485 Controller/
File: rs485_controller.kicad_sch
Title: Sensor Node Custom Board

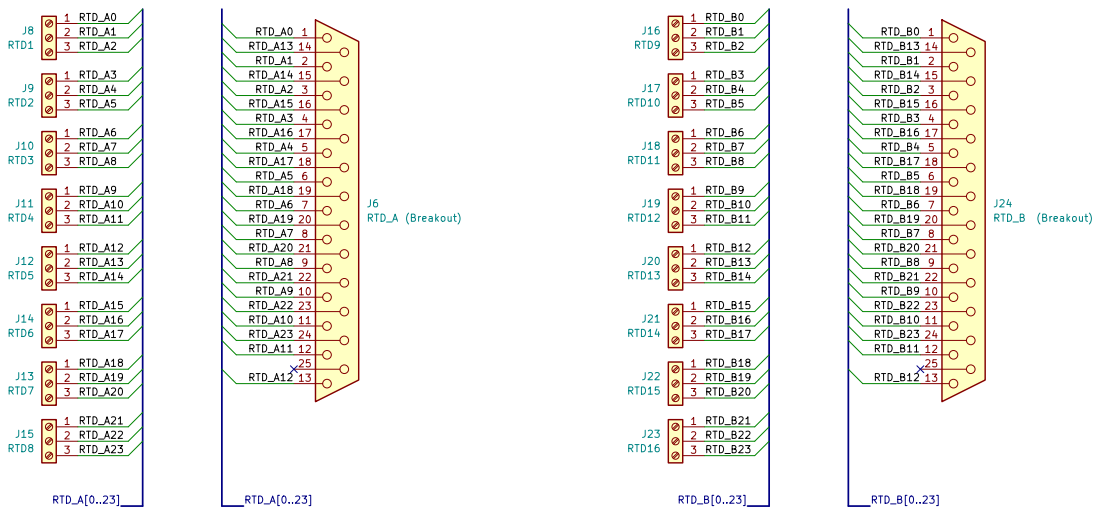
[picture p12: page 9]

Zadock Maloba
Octavia Carbon
Sheet: /IO Breakout Board/
File: io_breakout_board.kicad_sch
Title: Sensor Node Custom Board

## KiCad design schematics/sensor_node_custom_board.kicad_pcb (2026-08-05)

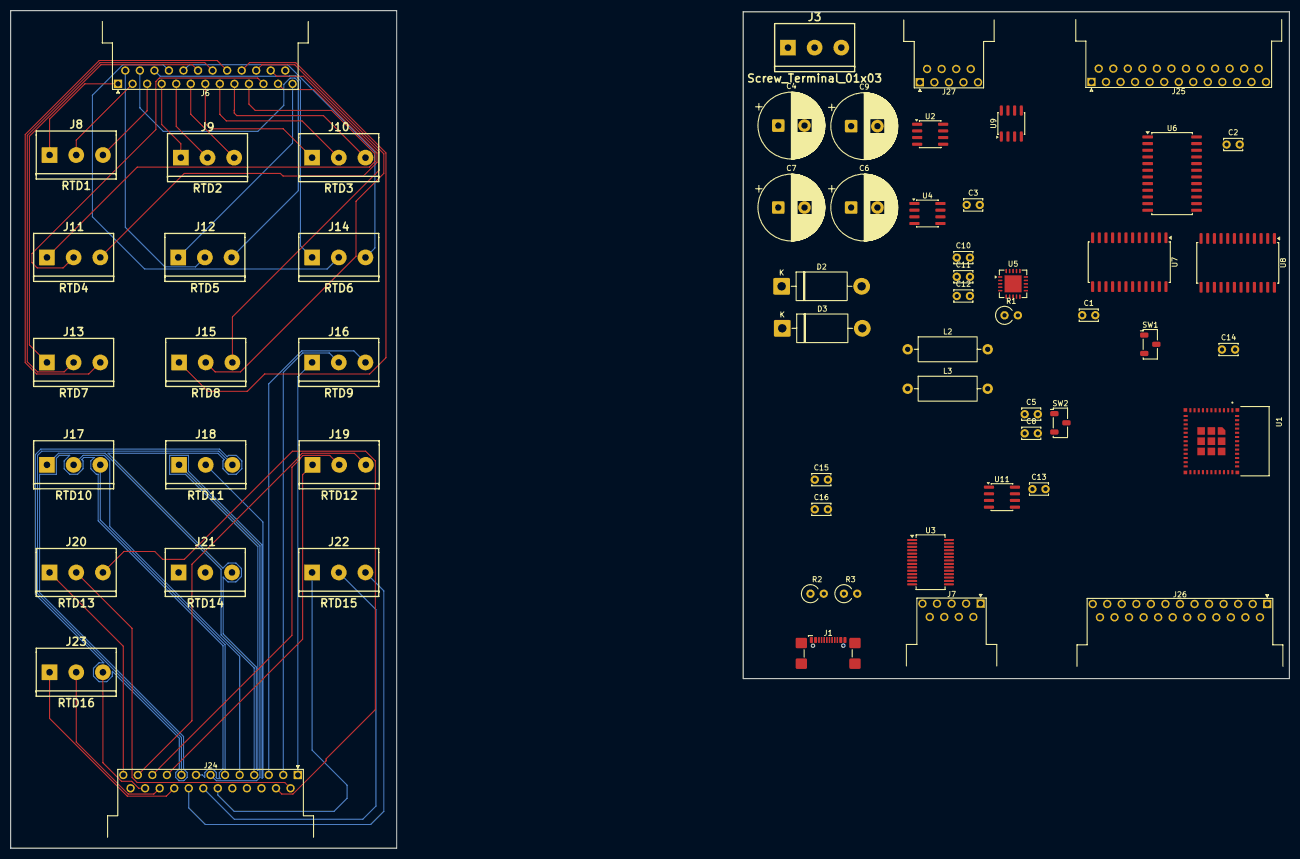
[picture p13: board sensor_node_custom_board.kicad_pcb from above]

Board: 2 copper layers, 243.5 x 159.5 mm, 59 parts (0 on the bottom side), 132 nets.

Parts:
C1, C2, C13, C14, C15, C16: 0.1uF; C_Disc_D3.4mm_W2.1mm_P2.50mm
C3, C10, C11: 10uF; C_Disc_D3.4mm_W2.1mm_P2.50mm
C4, C7: 470uF/50V; CP_Radial_D12.5mm_P5.00mm
C5, C8: 105; C_Disc_D3.4mm_W2.1mm_P2.50mm
C6: 330uF/35V; CP_Radial_D12.5mm_P5.00mm
C9: 180uF/35V; CP_Radial_D12.5mm_P5.00mm
C12: 10nF; C_Disc_D3.4mm_W2.1mm_P2.50mm
D2, D3: 1N5822; D_DO-201AD_P15.24mm_Horizontal
J1: USB_C_Receptacle_USB2.0_16P; USB_C_Receptacle_GCT_USB4110
J3: Screw_Terminal_01x03; mors_3p
J6: RTD_A (Breakout); DSUB-25_Socket_Horizontal_P2.77x2.54mm_EdgePinOffset9.40mm
J7: MODBUS RTU; DSUB-9_Socket_Horizontal_P2.77x2.54mm_EdgePinOffset9.40mm
J8: RTD1; mors_3p
J9: RTD2; mors_3p
J10: RTD3; mors_3p
J11: RTD4; mors_3p
J12: RTD5; mors_3p
J13: RTD7; mors_3p
J14: RTD6; mors_3p
J15: RTD8; mors_3p
J16: RTD9; mors_3p
J17: RTD10; mors_3p
J18: RTD11; mors_3p
J19: RTD12; mors_3p
J20: RTD13; mors_3p
J21: RTD14; mors_3p
J22: RTD15; mors_3p
J23: RTD16; mors_3p
J24: RTD_B (Breakout); DSUB-25_Socket_Horizontal_P2.77x2.54mm_EdgePinOffset9.40mm
J25: RTD_A; DSUB-25_Socket_Horizontal_P2.77x2.54mm_EdgePinOffset9.40mm
J26: RTD_B; DSUB-25_Socket_Horizontal_P2.77x2.54mm_EdgePinOffset9.40mm
J27: CAN; DSUB-9_Socket_Horizontal_P2.77x2.54mm_EdgePinOffset9.40mm
L2, L3: 68uH; L_Axial_L11.0mm_D4.5mm_P15.24mm_Horizontal_Fastron_MECC
R1: 4k; R_Axial_DIN0309_L9.0mm_D3.2mm_P2.54mm_Vertical
R2, R3: 5.1k; R_Axial_DIN0309_L9.0mm_D3.2mm_P2.54mm_Vertical
SW1: SW_ESP_ EN; Nidec_Copal_CAS-120A
SW2: SW_Nidec_CAS-120A1; Nidec_Copal_CAS-120A
U1: ESP32-PICO-MINI-02; MODULE_ESP32-PICO-MINI-02
U2: XL1509-5.0; SOIC-8_3.9x4.9mm_P1.27mm
U3: FT232RL; SSOP-28_5.3x10.2mm_P0.65mm
U4: XL1509-3.3; SOIC-8_3.9x4.9mm_P1.27mm
U5: MAX31865xTP; TQFN-20-1EP_5x5mm_P0.65mm_EP3.25x3.25mm
U6, U7, U8: CD74HC4067M; SOIC-24W_7.5x15.4mm_P1.27mm
U9: SN65HVD255D; SOIC-8_3.9x4.9mm_P1.27mm
U11: ISL3175E; SOIC-8_3.9x4.9mm_P1.27mm

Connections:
/Control Board/CAN Bus Controller/CANH: J27.7, U9.7 (CANH)
/Control Board/CAN Bus Controller/CANL: J27.2, U9.6 (CANL)
/Control Board/ESP_RXD0: U1.30 (RXD0), U3.5 (RXD), U11.1 (RO)
/Control Board/ESP_TXD0: U1.31 (TXD0), U3.1 (TXD), U11.4 (DI)
/Control Board/HSPI_CLK: U1.18 (IO14), U5.12 (SCLK)
/Control Board/HSPI_CS: U1.21 (IO15), U5.13 (~CS)
/Control Board/HSPI_MISO: U1.19 (IO12), U5.14 (SDO)
/Control Board/HSPI_MOSI: U1.20 (IO13), U5.11 (SDI)
/Control Board/ISL_DE: U1.16 (IO26), U11.3 (DE)
/Control Board/MCU/ESP_EN: SW1.2 (B), U1.8 (EN)
/Control Board/MUX_CTL0: U1.33 (IO19), U6.10 (S0), U7.10 (S0), U8.10 (S0)
/Control Board/MUX_CTL1: U1.26 (IO20), U6.11 (S1), U7.11 (S1), U8.11 (S1)
/Control Board/MUX_CTL2: U1.35 (IO21), U6.14 (S2), U7.14 (S2), U8.14 (S2)
/Control Board/MUX_CTL3: U1.34 (IO22), U6.13 (S3), U7.13 (S3), U8.13 (S3)
/Control Board/Power Supply/COM_GND: C1.2, C2.2, C3.2, C4.2, C5.2, C6.2, C7.2, C8.2, C9.2, C10.2, C11.2, C13.1, C14.2, C15.2, C16.2, D2.2 (A), D3.2 (A), J1.A1 (GND), J1.A12 (GND), J1.B1 (GND), J1.B12 (GND), J1.SH (SHIELD), J3.2, J27.3, R2.2, R3.2, SW1.1 (C), SW2.2 (B), U1.1 (GND), U1.2 (GND__1), U1.11 (GND__2), U1.14 (GND__3), U1.36 (GND__4), U1.37 (GND__5), U1.38 (GND__6), U1.39 (GND__7), U1.40 (GND__8), U1.41 (GND__9), U1.42 (GND__10), U1.43 (GND__11), U1.44 (GND__12), U1.45 (GND__13), U1.46 (GND__14), U1.47 (GND__15), U1.48 (GND__16), U1.49 (GND__17), U1.50 (GND__18), U1.51 (GND__19), U1.52 (GND__20), U1.53 (GND__21), U1.54 (GND__22), U1.55 (GND__23), U1.56 (GND__24), U1.57 (GND__25), U1.58 (GND__26), U1.59 (GND__27), U1.60 (GND__28), U1.61 (GND__29), U2.5 (GND), U2.6 (GND), U2.7 (GND), U2.8 (GND), U3.7 (GND), U3.18 (GND), U3.21 (GND), U3.25 (AGND), U4.5 (GND), U4.6 (GND), U4.7 (GND), U4.8 (GND), U5.10 (GND), U5.15 (DGND), U5.16 (GND), U5.21 (GND), U6.12 (GND), U7.12 (GND), U8.12 (GND), U9.2 (GND), U11.5 (GND)
/Control Board/Power Supply/POWER_ON: SW2.1 (C), U2.4 (~EN), U4.4 (~EN)
/Control Board/Power Supply/VBUS_3V3: C1.1, C2.1, C3.1, C6.1, C9.1, C10.1, C11.1, C13.2, C14.1, C15.1, C16.1, J27.9, L2.2, L3.2, SW1.3 (A), U1.3 (3V3), U2.3 (FB), U3.4 (VCCIO), U3.20 (VCC), U4.3 (FB), U5.19 (DVDD), U5.20 (VDD), U6.24 (VCC), U7.24 (VCC), U8.24 (VCC), U9.3 (VCC), U11.8 (VCC)
/Control Board/Power Supply/VBUS_24: C4.1, C5.1, C7.1, C8.1, J3.1, U2.1 (VIN), U4.1 (VIN)
/Control Board/Programmer & Debugger/USBD+: J1.A6 (D+), J1.B6 (D+), U3.15 (USBD+)
/Control Board/Programmer & Debugger/USBD-: J1.A7 (D-), J1.B7 (D-), U3.16 (USBD-)
/Control Board/RS-485 Controller/MODBUS_TA: J7.8, U11.6 (A)
/Control Board/RS-485 Controller/MODBUS_TB: J7.3, U11.7 (B)
/Control Board/Sensor IO/F+0: J25.1, U7.9 (I0)
/Control Board/Sensor IO/F+1: J25.4, U7.8 (I1)
/Control Board/Sensor IO/F+2: J25.7, U7.7 (I2)
/Control Board/Sensor IO/F+3: J25.10, U7.6 (I3)
/Control Board/Sensor IO/F+4: J25.13, U7.5 (I4)
/Control Board/Sensor IO/F+5: J25.16, U7.4 (I5)
/Control Board/Sensor IO/F+6: J25.19, U7.3 (I6)
/Control Board/Sensor IO/F+7: J25.22, U7.2 (I7)
/Control Board/Sensor IO/F+8: J26.1, U7.23 (I8)
/Control Board/Sensor IO/F+9: J26.4, U7.22 (I9)
/Control Board/Sensor IO/F+10: J26.7, U7.21 (I10)
/Control Board/Sensor IO/F+11: J26.10, U7.20 (I11)
/Control Board/Sensor IO/F+12: J26.13, U7.19 (I12)
/Control Board/Sensor IO/F+13: J26.16, U7.18 (I13)
/Control Board/Sensor IO/F+14: J26.19, U7.17 (I14)
/Control Board/Sensor IO/F+15: J26.22, U7.16 (I15)
/Control Board/Sensor IO/MAX_FORCE+: U5.5 (FORCE+), U5.6 (FORCE2), U7.1 (COM)
/Control Board/Sensor IO/MAX_RTDIN+: C12.1, U5.7 (RTDIN+), U6.1 (COM)
/Control Board/Sensor IO/MAX_RTDIN-: C12.2, U5.8 (RTDIN-), U5.9 (FORCE-), U8.1 (COM)
/Control Board/Sensor IO/RTDIN+0: J25.2, U6.9 (I0)
/Control Board/Sensor IO/RTDIN+1: J25.5, U6.8 (I1)
/Control Board/Sensor IO/RTDIN+2: J25.8, U6.7 (I2)
/Control Board/Sensor IO/RTDIN+3: J25.11, U6.6 (I3)
/Control Board/Sensor IO/RTDIN+4: J25.14, U6.5 (I4)
/Control Board/Sensor IO/RTDIN+5: J25.17, U6.4 (I5)
/Control Board/Sensor IO/RTDIN+6: J25.20, U6.3 (I6)
/Control Board/Sensor IO/RTDIN+7: J25.23, U6.2 (I7)
/Control Board/Sensor IO/RTDIN+8: J26.2, U6.23 (I8)
/Control Board/Sensor IO/RTDIN+9: J26.5, U6.22 (I9)
/Control Board/Sensor IO/RTDIN+10: J26.8, U6.21 (I10)
/Control Board/Sensor IO/RTDIN+11: J26.11, U6.20 (I11)
/Control Board/Sensor IO/RTDIN+12: J26.14, U6.19 (I12)
/Control Board/Sensor IO/RTDIN+13: J26.17, U6.18 (I13)
/Control Board/Sensor IO/RTDIN+14: J26.20, U6.17 (I14)
/Control Board/Sensor IO/RTDIN+15: J26.23, U6.16 (I15)
/Control Board/Sensor IO/RTDIN-0: J25.3, U8.9 (I0)
/Control Board/Sensor IO/RTDIN-1: J25.6, U8.8 (I1)
/Control Board/Sensor IO/RTDIN-2: J25.9, U8.7 (I2)
/Control Board/Sensor IO/RTDIN-3: J25.12, U8.6 (I3)
/Control Board/Sensor IO/RTDIN-4: J25.15, U8.5 (I4)
/Control Board/Sensor IO/RTDIN-5: J25.18, U8.4 (I5)
/Control Board/Sensor IO/RTDIN-6: J25.21, U8.3 (I6)
/Control Board/Sensor IO/RTDIN-7: J25.24, U8.2 (I7)
/Control Board/Sensor IO/RTDIN-8: J26.3, U8.23 (I8)
/Control Board/Sensor IO/RTDIN-9: J26.6, U8.22 (I9)
/Control Board/Sensor IO/RTDIN-10: J26.9, U8.21 (I10)
/Control Board/Sensor IO/RTDIN-11: J26.12, U8.20 (I11)
/Control Board/Sensor IO/RTDIN-12: J26.15, U8.19 (I12)
/Control Board/Sensor IO/RTDIN-13: J26.18, U8.18 (I13)
/Control Board/Sensor IO/RTDIN-14: J26.21, U8.17 (I14)
/Control Board/Sensor IO/RTDIN-15: J26.24, U8.16 (I15)
/Control Board/TWAI_RX: U1.24 (IO4), U9.4 (RXD)
/Control Board/TWAI_TX: U1.29 (IO5), U9.1 (TXD)
/Control Board/~ISL_RE: U1.17 (IO27), U11.2 (~RE)
/Control Board/~MUX_E: U1.15 (IO25), U6.15 (~E), U7.15 (~E), U8.15 (~E)
/Control Board/~SEN_DRDY: U1.10 (I35), U5.18 (~DRDY)
/IO Breakout Board/RTD_A0: J6.1, J8.1
/IO Breakout Board/RTD_A1: J6.2, J8.2
/IO Breakout Board/RTD_A2: J6.3, J8.3
/IO Breakout Board/RTD_A3: J6.4, J9.1
/IO Breakout Board/RTD_A4: J6.5, J9.2
/IO Breakout Board/RTD_A5: J6.6, J9.3
/IO Breakout Board/RTD_A6: J6.7, J10.1
/IO Breakout Board/RTD_A7: J6.8, J10.2
/IO Breakout Board/RTD_A8: J6.9, J10.3
/IO Breakout Board/RTD_A9: J6.10, J11.1
/IO Breakout Board/RTD_A10: J6.11, J11.2
/IO Breakout Board/RTD_A11: J6.12, J11.3
/IO Breakout Board/RTD_A12: J6.13, J12.1
/IO Breakout Board/RTD_A13: J6.14, J12.2
/IO Breakout Board/RTD_A14: J6.15, J12.3
/IO Breakout Board/RTD_A15: J6.16, J14.1
/IO Breakout Board/RTD_A16: J6.17, J14.2
/IO Breakout Board/RTD_A17: J6.18, J14.3
/IO Breakout Board/RTD_A18: J6.19, J13.1
/IO Breakout Board/RTD_A19: J6.20, J13.2
/IO Breakout Board/RTD_A20: J6.21, J13.3
/IO Breakout Board/RTD_A21: J6.22, J15.1
/IO Breakout Board/RTD_A22: J6.23, J15.2
/IO Breakout Board/RTD_A23: J6.24, J15.3
/IO Breakout Board/RTD_B0: J16.1, J24.1
/IO Breakout Board/RTD_B1: J16.2, J24.2
/IO Breakout Board/RTD_B2: J16.3, J24.3
/IO Breakout Board/RTD_B3: J17.1, J24.4
/IO Breakout Board/RTD_B4: J17.2, J24.5
/IO Breakout Board/RTD_B5: J17.3, J24.6
/IO Breakout Board/RTD_B6: J18.1, J24.7
/IO Breakout Board/RTD_B7: J18.2, J24.8
/IO Breakout Board/RTD_B8: J18.3, J24.9
/IO Breakout Board/RTD_B9: J19.1, J24.10
/IO Breakout Board/RTD_B10: J19.2, J24.11
/IO Breakout Board/RTD_B11: J19.3, J24.12
/IO Breakout Board/RTD_B12: J20.1, J24.13
/IO Breakout Board/RTD_B13: J20.2, J24.14
/IO Breakout Board/RTD_B14: J20.3, J24.15
/IO Breakout Board/RTD_B15: J21.1, J24.16
/IO Breakout Board/RTD_B16: J21.2, J24.17
/IO Breakout Board/RTD_B17: J21.3, J24.18
/IO Breakout Board/RTD_B18: J22.1, J24.19
/IO Breakout Board/RTD_B19: J22.2, J24.20
/IO Breakout Board/RTD_B20: J22.3, J24.21
/IO Breakout Board/RTD_B21: J23.1, J24.22
/IO Breakout Board/RTD_B22: J23.2, J24.23
/IO Breakout Board/RTD_B23: J23.3, J24.24
unnamed: D2.1 (K), L2.1, U4.2 (OUT)
unnamed: D3.1 (K), L3.1, U2.2 (OUT)
unnamed: J1.A5 (CC1), R2.1
unnamed: J1.B5 (CC2), R3.1
unnamed: R1.1, U5.1 (BIAS), U5.2 (REFIN+)
unnamed: R1.2, U5.3 (REFIN-), U5.4 (ISENSOR)

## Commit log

2026-08-05 Plot revision 1 - partial submission
    [can_bus_controller.kicad_sch, mcu.kicad_sch, programmer_and_debugger.kicad_sch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]
2026-08-05 Add board render
2026-08-05 Add more board render images
